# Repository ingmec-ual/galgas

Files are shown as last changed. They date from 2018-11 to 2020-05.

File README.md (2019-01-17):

# galgas
Esquemas y firmware de sistemas de medición de tensiones con galgas

Contenido de los directorios: 

  * `galgas-didacticas`: Esquemas en formato Eagle CAD y PDF.
  * `galgas_firmware`: Firmware con proyecto AtmelStudio, usando librería C++ de Arduino IDE. El programa principal es [Sketch.cpp](https://github.com/ingmec-ual/galgas/blob/master/galgas_firmware/galgas_firmware/firmware/Sketch.cpp).

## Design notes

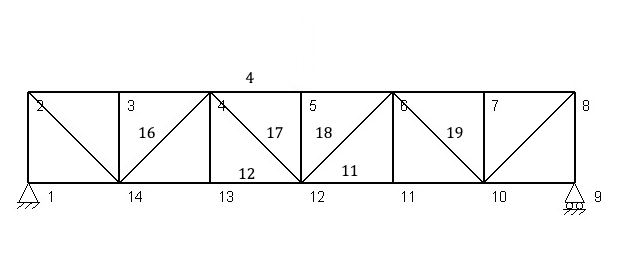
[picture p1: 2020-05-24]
matlab/puente.jpg

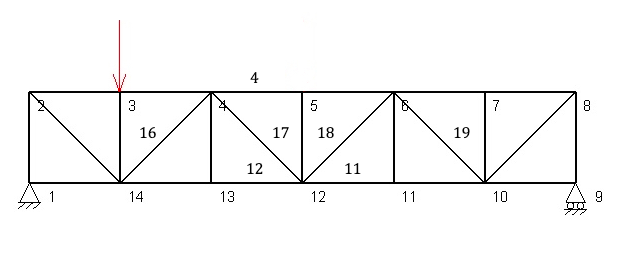
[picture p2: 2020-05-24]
matlab/caso2.jpg

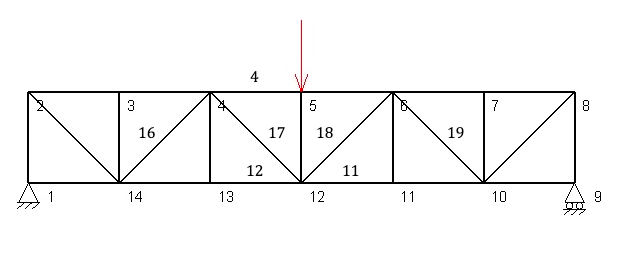
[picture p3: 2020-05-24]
matlab/caso4.jpg

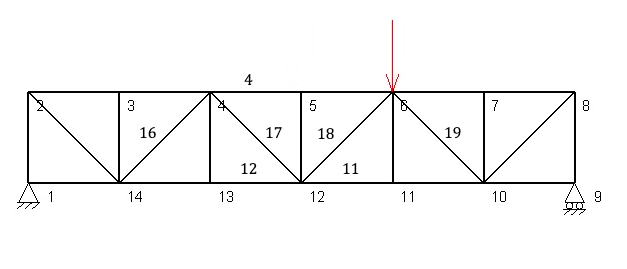
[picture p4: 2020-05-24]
matlab/caso5.jpg

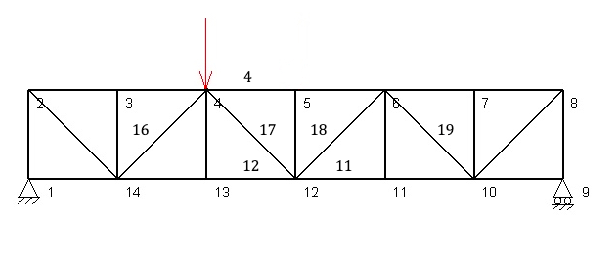
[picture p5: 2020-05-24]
matlab/caso3.jpg

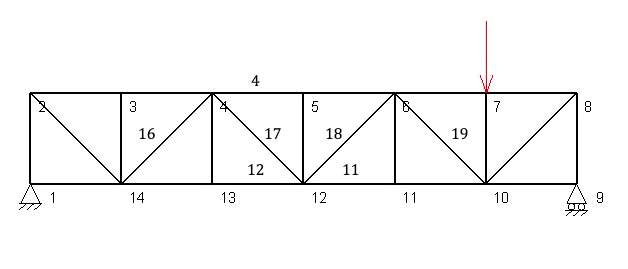
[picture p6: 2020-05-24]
matlab/caso6.jpg

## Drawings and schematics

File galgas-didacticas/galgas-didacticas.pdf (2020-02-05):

## Parte analógica

# Módulo: Galgas + tiras LED PWM

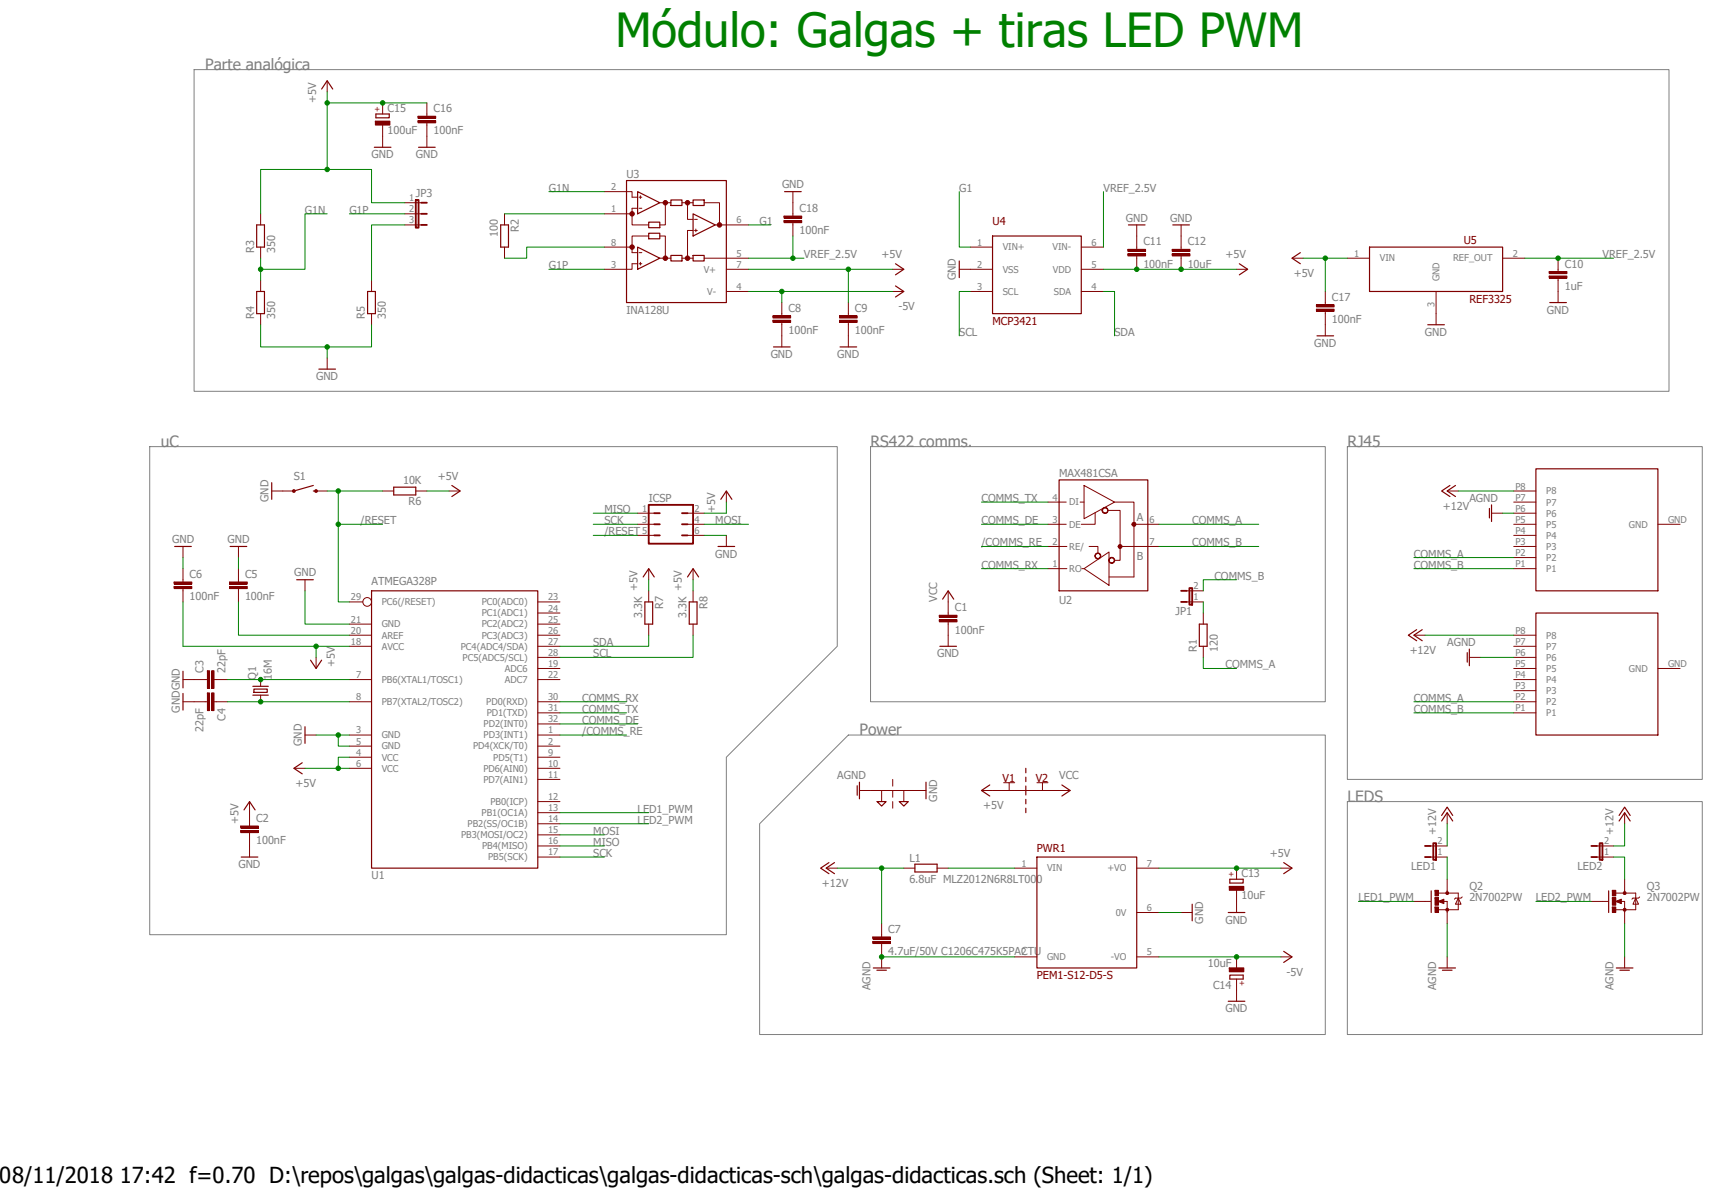
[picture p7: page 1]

08/11/2018 17:42 f=0.70 D:\repos\galgas\galgas-didacticas\galgas-didacticas-sch\galgas-didacticas.sch (Sheet: 1/1)

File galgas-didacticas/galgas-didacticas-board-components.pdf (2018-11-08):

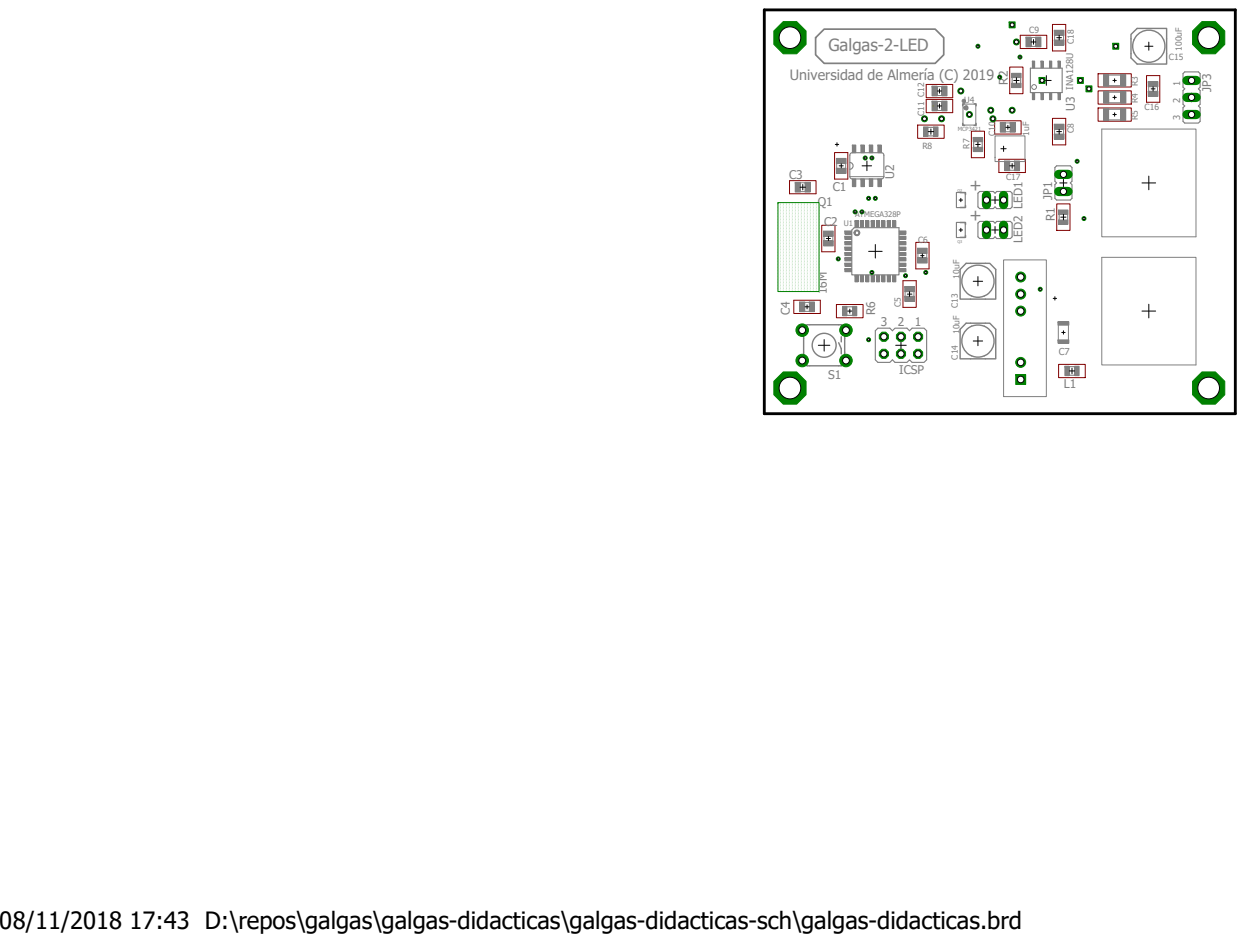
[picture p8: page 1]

08/11/2018 17:43 D:\repos\galgas\galgas-didacticas\galgas-didacticas-sch\galgas-didacticas.brd

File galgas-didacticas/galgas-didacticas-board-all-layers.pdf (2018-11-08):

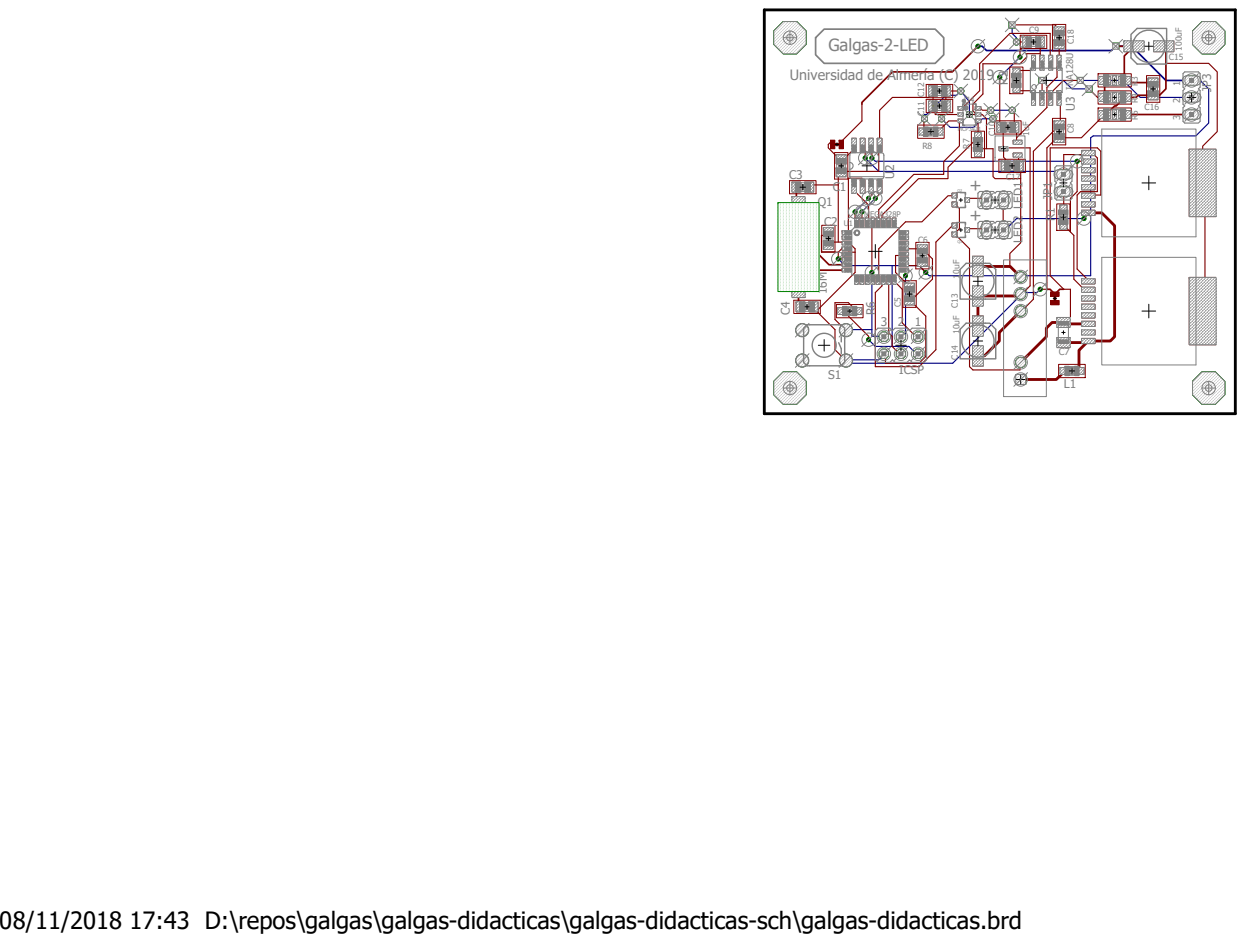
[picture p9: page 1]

08/11/2018 17:43 D:\repos\galgas\galgas-didacticas\galgas-didacticas-sch\galgas-didacticas.brd

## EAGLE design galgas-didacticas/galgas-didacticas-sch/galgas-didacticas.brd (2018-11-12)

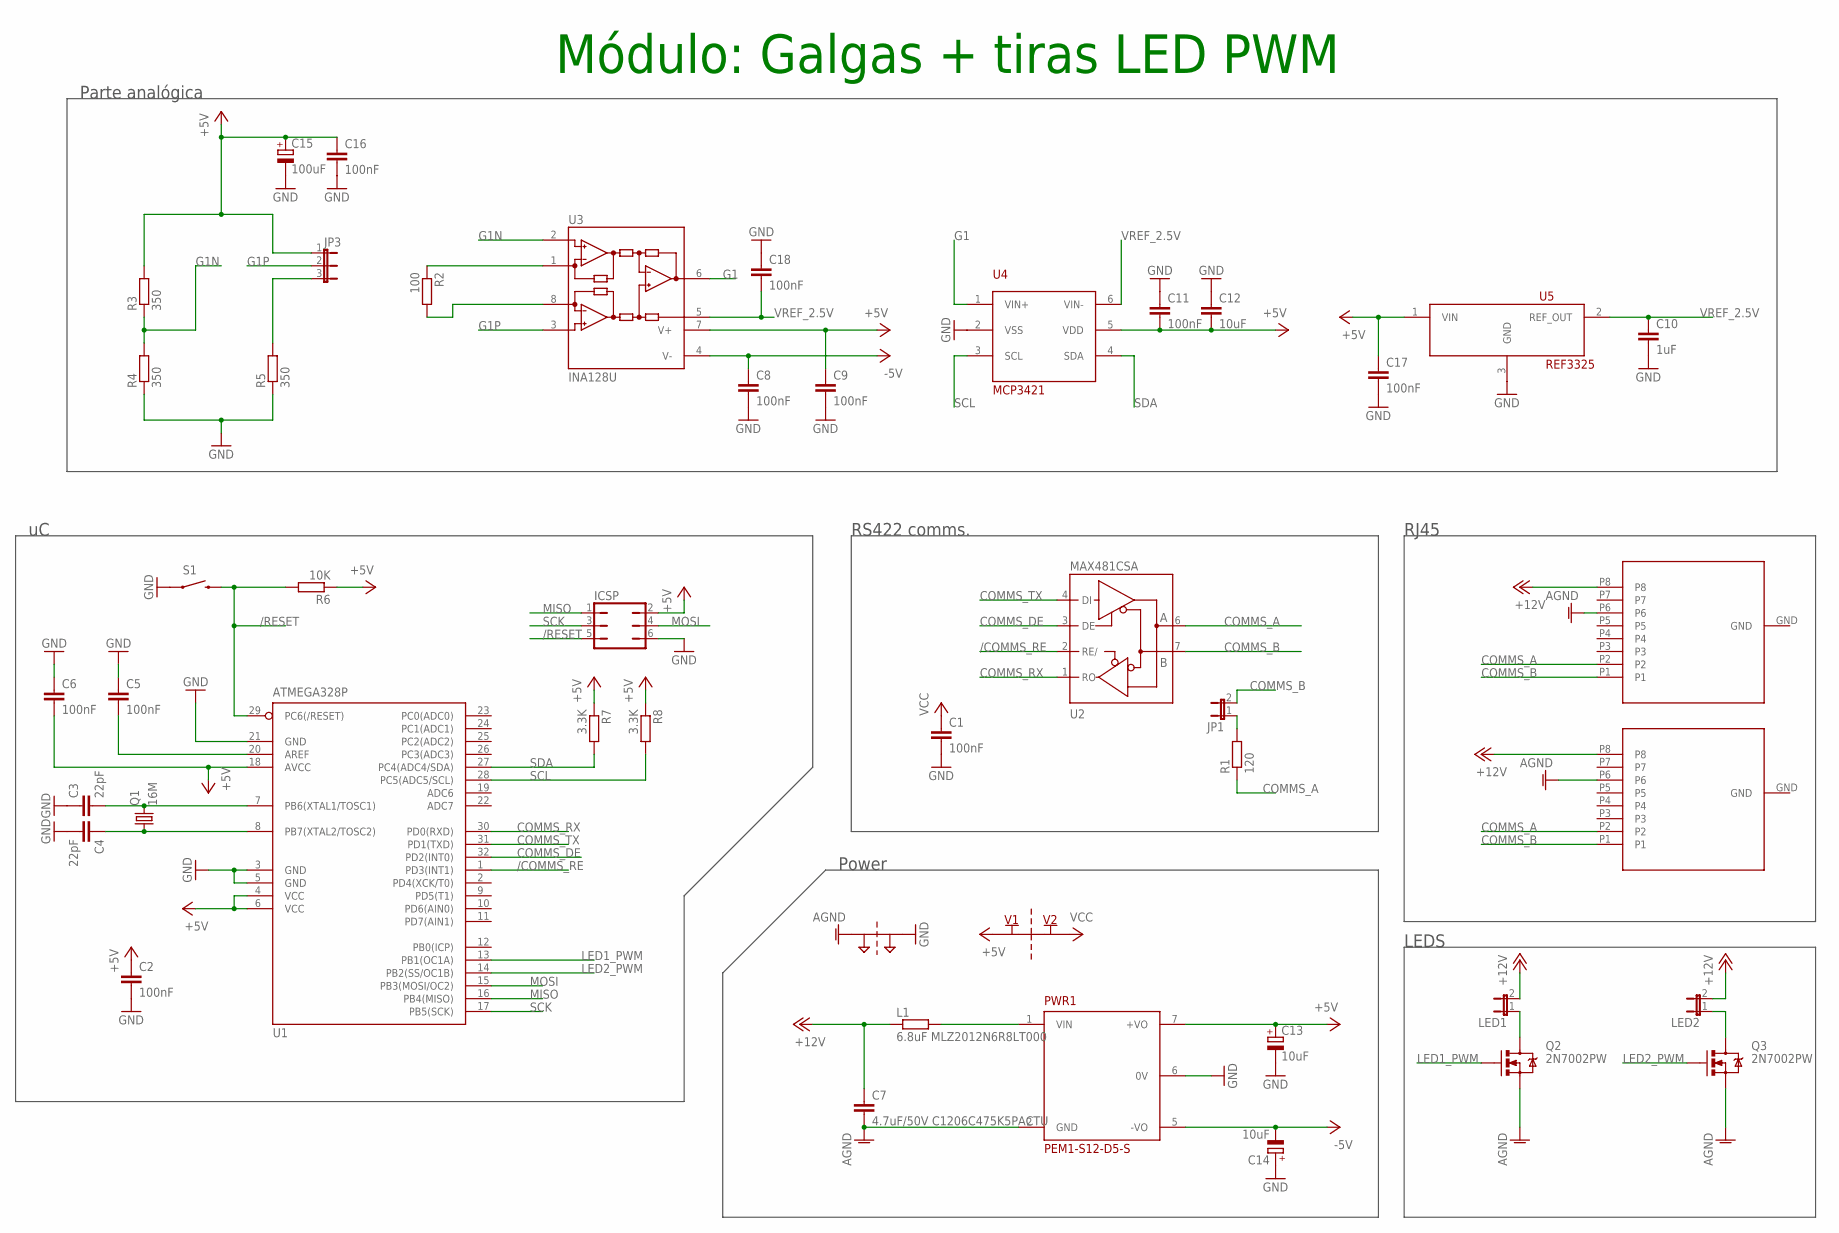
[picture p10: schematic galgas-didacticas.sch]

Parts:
C1, C2, C5, C6, C8, C9, C11, C16, C17, C18: 100nF; C0805
C3, C4: 22pF; C0805
C7: 4.7uF/50V C1206C475K5PACTU; C1206K
C10: 1uF; C0805
C12: 10uF; C0805
C13, C14: 10uF; 153CLV-0505
C15: 100uF; 153CLV-0505
ICSP: JP3Q
J1, J2: RJ45_DIRECT
JP1: JP1E; JP1
JP3: JP2E; JP2
L1: 6.8uF MLZ2012N6R8LT000; R0805W
LED1, LED2: JP1E; JP1
PT1: 2PT_GND_TIE
PWR1: PEM1-S12-D5-S; PEM1-S
Q1: 16M; HC49UP
Q2, Q3: 2N7002PW; SOT323
R1: 120; R0805W
R2: 100; R0805W
R3, R4, R5: 350; R1206W
R6: 10K; R0805W
R7, R8: 3.3K; R0805W
S1: SWITCH-MOMENTARY-2PTH; TACTILE-PTH
U1: ATMEGA328P; TQFP32-08
U2: MAX481CSA; SO08
U3: INA128U; SO08
U4: MCP3421; SOT-23-6
U5: REF3325; SOT-23
U$2: SUPPLY_CONNECT; 2PT_GND_TIE

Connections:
+5V: C2.1, C6.2, C9.1, C11.2, C12.2, C13.+, C15.+, C16.1, C17.1, ICSP.2, JP3.1, PWR1.7 (+VO), R3.2, R6.1, R7.1, R8.1, U1.4 (VCC), U1.6 (VCC), U1.18 (AVCC), U3.7 (V+), U4.5 (VDD), U5.1 (VIN), U$2.P$1
+12V: C7.1, J1.P8, J2.P8, L1.1, LED1.2, LED2.2
-5V: C8.1, C14.-, PWR1.5 (-VO), U3.4 (V-)
/COMMS_RE: U1.1 (PD3(INT1)), U2.2 (RE/)
/RESET: ICSP.5, R6.2, S1.3 (2), U1.29 (PC6(/RESET))
AGND: C7.2, J1.P6, J2.P6, PT1.P$1, PWR1.2 (GND), Q2.2 (S), Q3.2 (S)
COMMS_A: J1.P2, J2.P2, R1.1, U2.6 (A)
COMMS_B: J1.P1, J2.P1, JP1.2, U2.7 (B)
COMMS_DE: U1.32 (PD2(INT0)), U2.3 (DE)
COMMS_RX: U1.30 (PD0(RXD)), U2.1 (RO)
COMMS_TX: U1.31 (PD1(TXD)), U2.4 (DI)
G1: U3.6 (OUT), U4.1 (VIN+)
G1N: R3.1, R4.2, U3.2 (-IN)
G1P: JP3.2, U3.3 (+IN)
GND: C1.2, C2.2, C3.1, C4.2, C5.1, C6.1, C8.2, C9.2, C10.2, C11.1, C12.1, C13.-, C14.+, C15.-, C16.2, C17.2, C18.1, ICSP.6, J1.GND, J2.GND, PT1.P$2, PWR1.6 (0V), R4.1, R5.1, S1.1, U1.3 (GND), U1.5 (GND), U1.21 (GND), U2.5 (GND), U4.2 (VSS), U5.3 (GND)
LED1_PWM: Q2.1 (G), U1.13 (PB1(OC1A))
LED2_PWM: Q3.1 (G), U1.14 (PB2(SS/OC1B))
MISO: ICSP.1, U1.16 (PB4(MISO))
MOSI: ICSP.4, U1.15 (PB3(MOSI/OC2))
unnamed: JP1.1, R1.2
unnamed: LED1.1, Q2.3 (D)
unnamed: C3.2, Q1.2, U1.7 (PB6(XTAL1/TOSC1))
unnamed: C4.1, Q1.1, U1.8 (PB7(XTAL2/TOSC2))
unnamed: C5.2, U1.20 (AREF)
unnamed: L1.2, PWR1.1 (VIN)
unnamed: R2.1, U3.1 (RG)
unnamed: R2.2, U3.8 (RG)
unnamed: LED2.1, Q3.3 (D)
unnamed: JP3.3, R5.2
SCK: ICSP.3, U1.17 (PB5(SCK))
SCL: R8.2, U1.28 (PC5(ADC5/SCL)), U4.3 (SCL)
SDA: R7.2, U1.27 (PC4(ADC4/SDA)), U4.4 (SDA)
VCC: C1.1, U2.8 (VCC), U$2.P$2
VREF_2.5V: C10.1, C18.2, U3.5 (REF), U4.6 (VIN-), U5.2 (REF_OUT)

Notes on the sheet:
LEDS
RJ45
RS422 comms.
Power
Parte analógica
Módulo: Galgas + tiras LED PWM

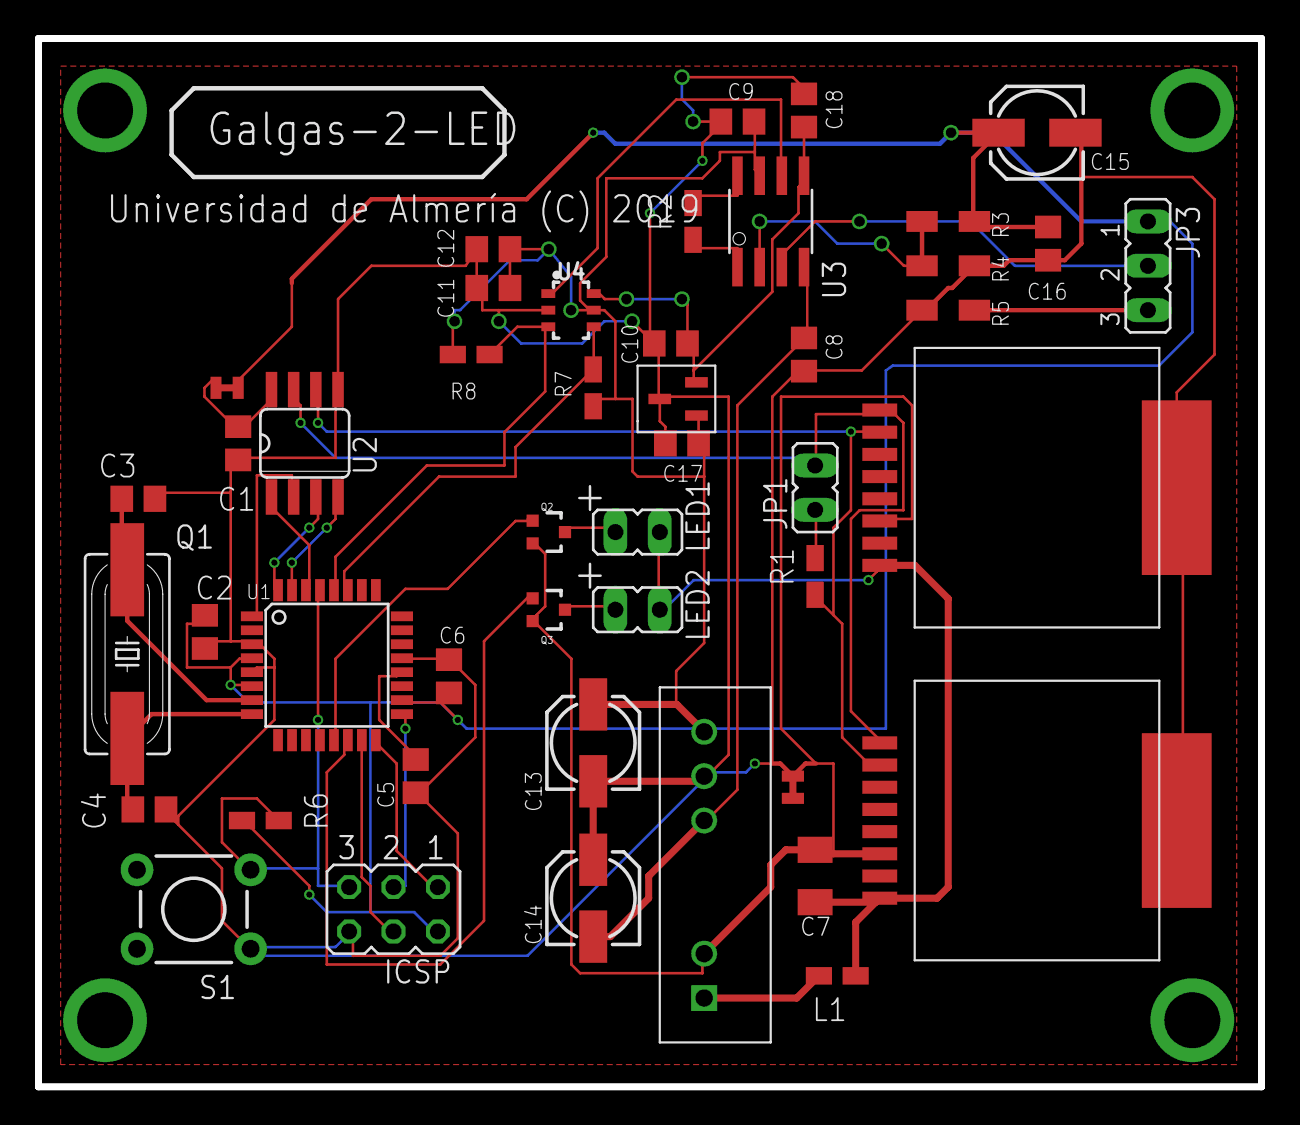
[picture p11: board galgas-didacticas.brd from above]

Board: 2 copper layers, 70.0 x 60.0 mm, 46 parts (0 on the bottom side), 34 nets.

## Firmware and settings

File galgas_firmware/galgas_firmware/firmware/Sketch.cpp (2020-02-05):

/*
  Sketch.cpp - Main file for "Didactic Strain Gauges-LED System"
  Copyright (c) 2018-2019 University of Almeria.  All right reserved.

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
  You should have received a copy of the GNU Lesser General Public
  License along with this library; if not, write to the Free Software
  Foundation, Inc., 51 Franklin St, Fifth Floor, Boston, MA  02110-1301  USA
*/

// Firmware designed for ATMEGA328P
// Note: to enable sprintf() of doubles/floats, link with these flags:
// -Wl,-u,vfprintf -lprintf_flt -lm

#include <Arduino.h>
#include <EEPROM.h>
#include <Wire.h>
#include "MCP342X.h"

// Uncomment to enable sending debug text messages to the serial console.
// do NOT leave enabled for production, since several devices would try 
// to write simultaneously to the RS485 bus without arbitration.
//#define SERIAL_DEBUG_MSGS

// LEDs:
constexpr int LED1_PIN = 9; // uC pin 13, PB1
constexpr int LED2_PIN = 10; // uC pin 14, PB2

constexpr int SERIAL_DE_PIN  = 2; // uC pin 32, PD2
constexpr int SERIAL_nRE_PIN = 3; // uC pin 1, PD3

// The ADC:
static MCP342X adc;
static bool adc_init_ok = false;
static const auto ADC_GAIN = MCP342X_GAIN_1X;
static uint8_t MY_ID = 0xff; // My unique board ID, stored in EEPROM

// The residual strain, acquired after reset:
static int16_t adc_zero_strain_offset = 0;

// Last measured strain, in ADC bit units (after offset compensation):
static int32_t measured_real_strain = 0;

// Calculated such as V_adc=0.3 ==> 100% of PWM LED output
static double STRAIN_TO_PWM_CONST = 255.5/ (0.3 * ((2<<15 - 1) / 2.5));

static double threshold_strain_leds = 100;


// func. decls:
static void process_sensors_leds();
static void process_command(const char*cmd);
static void do_led_ramp_up_down(int led_id, int delay_speed_ms = 6);
static void rs485_enable_tx();
static void rs485_enable_rx();
static void rs485_send_string(const char* s);
static uint8_t id_read(); // Read "my ID" from EEPROM
static void id_write(uint8_t id); // write "my ID" to EEPROM


void setup()
{
	// Flash LEDs at start up:
	do_led_ramp_up_down(LED1_PIN, 3);
	do_led_ramp_up_down(LED2_PIN, 3);

	// Init I2C bus:
	Wire.begin();
	// Use max I2C speed (400 kHz)
	TWBR = 12;

	// Read ID from eeprom
	MY_ID = id_read();

	// Configure RS485 control outputs:
	pinMode(SERIAL_DE_PIN, OUTPUT);
	pinMode(SERIAL_nRE_PIN, OUTPUT);
	rs485_enable_rx();

	// Init serial port:
	Serial.begin(115200);

	// read timeout (ms)
	Serial.setTimeout(5);

	// wait for Serial comms to become ready
	while (!Serial) {}
		
}

void loop()
{
	// Test connection to ADC once after boot up:
	// --------------------------------------------------
	if (!adc_init_ok)
	{
#ifdef SERIAL_DEBUG_MSGS
		rs485_send_string("# Testing ADC connection...");
#endif

		adc_init_ok = adc.testConnection();
		if (adc_init_ok)
		{
#ifdef SERIAL_DEBUG_MSGS
			rs485_send_string("# MCP342X connection successful!");
#endif

			adc.configure(
				MCP342X_MODE_CONTINUOUS |
				MCP342X_CHANNEL_1 |
				MCP342X_SIZE_16BIT |
				ADC_GAIN
				);

#ifdef SERIAL_DEBUG_MSGS
			rs485_enable_tx();
			Serial.print("# ADC config register=");
			Serial.println(adc.getConfigRegShdw(), HEX);
			Serial.flush();
			rs485_enable_rx();
#endif

			// Read a few samples (a discard them) waiting for the 
			// analog value to stabilize after reset, then take it as 
			// the "residual strain" offset value:
			// (16bit -> continuous rate of 15 SPS)
			for (int i=0;i<15;i++)
			{
				adc.startConversion();
				adc.getResult(&adc_zero_strain_offset);
			}

#ifdef SERIAL_DEBUG_MSGS
			rs485_enable_tx();
			Serial.print("# Using ADC offset value=");
			Serial.println(adc_zero_strain_offset);
			Serial.flush();
			rs485_enable_rx();
#endif
		}
		else
		{
#ifdef SERIAL_DEBUG_MSGS
			rs485_send_string("# MCP342X connection failed! Retrying in 1 second...");
#endif
			delay(1000);
			return;
		}
	}
	

	// Main ADC reading task:
	process_sensors_leds();

	// check for commands from the PC:
	String sCmd = Serial.readStringUntil('\n');
	if (sCmd.length()>2)
	{
		process_command(sCmd.c_str());
	}
}

// Main task: read ADC and flash LEDs accordingly
void process_sensors_leds()
{
	int16_t  adc_value;
	adc.startConversion();
	adc.getResult(&adc_value);
	
	// Strain is measured - offset (residual structural strain)
	measured_real_strain = adc_value - adc_zero_strain_offset;
	
	// Convert to PWM (0-255)
	double pwm_value_f= .0;
	if (fabs(measured_real_strain)>threshold_strain_leds)
	{
		pwm_value_f = STRAIN_TO_PWM_CONST * measured_real_strain;
	}

	// Saturate:
	const bool is_negative = (pwm_value_f<0);
	if (pwm_value_f<0) pwm_value_f=-pwm_value_f;
	if (pwm_value_f>255) pwm_value_f = 255;
	uint8_t pwm_value = static_cast<uint8_t>(pwm_value_f);
	
	// TODO: positive / negative, one LED or the other one.
	analogWrite(is_negative ? LED2_PIN : LED1_PIN, pwm_value);
	analogWrite(is_negative ? LED1_PIN : LED2_PIN, 0);
}


void do_led_ramp_up_down(int led_id, int delay_speed_ms)
{
	pinMode(led_id, OUTPUT);

	for (int pc = 0; pc <255; pc++)
	{
		analogWrite(led_id, pc);
		delay(delay_speed_ms);
	}
	for (int pc = 255; pc >0; pc--)
	{
		analogWrite(led_id, pc);
		delay(delay_speed_ms);
	}

}

void rs485_enable_tx()
{
	digitalWrite(SERIAL_DE_PIN, true);
	digitalWrite(SERIAL_nRE_PIN, true);
}

void rs485_enable_rx()
{
	digitalWrite(SERIAL_DE_PIN, false);
	digitalWrite(SERIAL_nRE_PIN, false);
}

void rs485_send_string(const char* s)
{
	rs485_enable_tx();
	Serial.print("TX:");
	Serial.println(s);
	Serial.flush();
	rs485_enable_rx();
}

// Read "my ID" from EEPROM
uint8_t id_read()
{
	return EEPROM.read(0x00);
}

// write "my ID" to EEPROM
void id_write(uint8_t id)
{
	EEPROM.write(0x00,id);
}

// Forward declaration of command functions:
static void do_cmd_id();
static void do_cmd_get(const char* varname);
static void do_cmd_set(const char* varname, double value);
static void do_cmd_setid(uint8_t new_id);

// Checks whether "str" starts with "substr"
static inline bool startsWith(const char* str, const char* substr)
{
	return !strncasecmp(str,substr, strlen(substr));
}

/* Format of commands:
*
* TO <ID> <CMD> <ARGS...>
*
*/
void process_command(const char*cmd)
{
	// Windows may be slow to reset the RTS signal so the hardware RS485 board parses our sent data, 
	// so make sure of inserting a "large" delay before we transmit anything:
	delay(30); // ms

	const auto len = strlen(cmd);
	if (len<3)
	{
		// wrong command? corrupt data?
		return;
	}

	if (!startsWith(cmd,"TO "))
	{
		rs485_send_string("does not start TO\n");
		return;
	}

	int target_id = 0xEE; // init to invalid value
	if (!sscanf(cmd+3,"%i",&target_id))
	{
		// Couldn't parse. Don't answer with an error code since we were not sure 
		// about whether the message was sent to this board (!).
		return;
	}

	if (target_id!=MY_ID)
	{
		// silently ignore this commands: it's not for us.
		return;
	}

	// advance cmd pointer to the next useful position:
	cmd+=3;
	while (*cmd!=' ')
	{
		if (*cmd=='\0') return;
		++cmd;
	}
	// Start with the next non blank char:
	cmd++;

	if (!strncmp(cmd,"ID",2))
	{
		return do_cmd_id();
	}
	if (!strncmp(cmd,"SETID ",6))
	{
		unsigned int new_id=0;
		if (1==sscanf(cmd+6,"%u",&new_id))
		{
			do_cmd_setid(new_id);
			return rs485_send_string("OK|ID changed.\n");
		}
		else
		{
			return rs485_send_string("ERROR|Cannot parse new ID value\n");
		}
	}
	if (!strncmp(cmd,"GET ",4))
	{
		return do_cmd_get(cmd+4);
	}

	char s[60];
	sprintf(s,"ERROR|Unrecognized command: `%.20s`\n", cmd);
	rs485_send_string(s);
}

void do_cmd_id()
{
	char s[60];
	sprintf(s,"OK|GalgasDidactivas ID=%u Build: " __TIMESTAMP__  "\n", id_read());
	rs485_send_string(s);
}


void do_cmd_setid(uint8_t new_id)
{
	id_write(new_id);
	MY_ID = new_id;
}

void do_cmd_get(const char* varname)
{
	char s[60];
	if (startsWith(varname,"STRAIN"))
	{
		sprintf(s,"OK|%i\n", measured_real_strain);
		return rs485_send_string(s);
	}
	if (startsWith(varname,"OFFSET"))
	{
		sprintf(s,"OK|%i\n", adc_zero_strain_offset);
		return rs485_send_string(s);
	}
	if (startsWith(varname,"PWM_CONST"))
	{
		sprintf(s,"OK|%u\n", static_cast<unsigned int>(STRAIN_TO_PWM_CONST*1000U));
		return rs485_send_string(s);
	}

	rs485_send_string("ERROR|GET: Unrecognized variable name\n");
}

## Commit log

2018-09-26 1st sch
    [galgas-didacticas.brd, galgas-didacticas.sch]
2018-11-06 First "final" version of the SCH
    [galgas-didacticas.brd, galgas-didacticas.sch]
2018-11-08 Board routing done
    [galgas-didacticas.brd, galgas-didacticas.sch]
2018-11-08 mejoras (más condensadores desacoplo, etc.)
    [galgas-didacticas.brd, galgas-didacticas.sch]
2018-11-12 planos GND
    [galgas-didacticas.brd]
2018-12-27 Import Arduino firmware to Atmel Studio
2018-12-27 led ramp function
2019-01-09 read ADC and flash LEDs accordingly
2019-01-17 Explicación de contenido directorios
2019-10-14 modifico imagines para que tengan el mismo tamaño
2019-10-14 modifico ortografía de los comentarios de los script
2019-10-14 creo la interfaz del programa
2019-10-15 puente cambia de color al estar sometido a compresion
2019-10-15 añado a la interfaz puente que cambia de color T/C
2019-10-22 añado comentarios de licencia
2019-10-23 primer intento de añadir temporizador
2019-11-22 Primera version clase de comunicaciones puerto serie
2020-02-03 corrección del peso y nombre de las barras sensorizadas
2020-02-04 añadir cuadro dialogo preguntando por el puerto serie
2020-02-05 LEDs: histeresis y apagar correctamente
    [Sketch.cpp]
2020-02-05 calculo de la epsilon a partir del voltaje
2020-02-10 Primer intento de checkbox
2020-02-13 segunda prueba de checkbox
2020-03-11 tabla todas las filas a la vez
2020-04-22 Segundo intento de boton simulacion/real
2020-04-22 soluciono problemas de unidades
2020-05-24 Nombrar las barras seleccionadas en las imagenes para que concuerden con la tabla
2020-05-24 cambio de tipo de medicion a tipo de resultados
2020-05-24 cambios en traccion y compresion para que salgan todas las barras

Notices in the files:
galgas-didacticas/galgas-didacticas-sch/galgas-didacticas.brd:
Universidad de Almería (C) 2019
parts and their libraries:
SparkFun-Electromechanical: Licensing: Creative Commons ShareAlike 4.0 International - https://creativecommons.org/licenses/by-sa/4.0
